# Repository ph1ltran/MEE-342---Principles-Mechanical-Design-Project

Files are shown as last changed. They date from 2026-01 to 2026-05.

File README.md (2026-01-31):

# MEE-342---Principles-Mechanical-Design-Project
Spring 2026 Semester - Group 13

Team members: Chase Winkelmann, Samantha Perek, Aza Zandieh, Phil Tran, Jon Seddon, Mahima Dattaguru

Main Report: should link to section-specific markdown files if needed (e.g., phase1.md, phase2.md, phase3.md).

[Phase 1 - System Understanding & Conceptual Design](https://github.com/ph1ltran/MEE-342---Principles-Mechanical-Design-Project/blob/main/phase1.md)

[Phase 2 - Detailed CAD Design & Engineering Analysis](https://github.com/ph1ltran/MEE-342---Principles-Mechanical-Design-Project/blob/main/phase2.md)

[Phase 3 - Prototyping, Testing, & Reflection](https://github.com/ph1ltran/MEE-342---Principles-Mechanical-Design-Project/blob/main/phase3.md)

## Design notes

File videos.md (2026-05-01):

# Links or text files pointing to hosted videos (e.g., YouTube links).

## Phase 1 Video
### Presentation
[Phase 1 Video](https://drive.google.com/file/d/13TvbBJ1mibGNusMHqBIKrH3WXQ0-EbeE/view?usp=sharing)

## Phase 2 Videos
### Presentation
[Phase 2 Video](https://drive.google.com/file/d/1klvvWlFgjiC-BsxMcsrkD3P9RIFnxmCl/view?usp=sharing)

### CAD/FEA Overview
https://github.com/user-attachments/assets/684e30f0-5ba8-4716-a56b-c2a44ff6e8ca

## Phase 3 Video
[Phase 3 Video](https://drive.google.com/file/d/16Yx-jXtcq2Cfcu958getdcPu3kcB0Ceg/view?usp=sharing)

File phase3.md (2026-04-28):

## Prototype Pictures:

Prototype Picture 1
Prototype Picture 2

## Fabrication Details:
Number of Parts: 2

Units: inches

Dimensions (WxLxH):

Support: 6x6x7

Holder: 6x2x3

Infill Density: 100%

Color: Grey

Number of Reprints: None

## Assembly Procedure:
1. Align the hole of the device holder between the two holes of the angled support. Ensure that the holder has the correct orientation and is facing the right direction.

2. Insert the threaded bolt through the hole, joining the holder to the support.

3. Once the bolt has been completely inserted, thread the wingnut onto the end of the bolt and tighten until the holder is no longer loose and its position remains fixed.

4. To change the holder’s position, simply loosen the wingnut to adjust the position before tightening the wingnut once again.

## Assembly Challenges:
The first challenge encountered in the assembly process was exporting the CAD model to an STL file as required by the FSE 3D Print Lab. Since the original CAD model was designed using the student version of ANSYS DesignModeler in order to facilitate the FEA procedures in Phase 2, exporting to an STL file was initially not an option. Multiple remedies to this obstacle were considered, such as transferring the model over to SpaceClaim for export or finding individuals with the full version of ANSYS who could then export the model to an STL file. Eventually, it was decided to redesign the model in SolidWorks while referencing the ANSYS model for the original design dimensions. This allowed the model to finally be exported to an STL file for 3D printing.

The second challenge encountered was that the bolt was not able to be smoothly inserted into the hole joining the holder to the support, due to insufficient tolerance in the dimensions of the original design. However, this turned out to not be a significant problem, because applying sufficient force allowed the bolt to be completely inserted while firmly securing the holder to the support with the tightening of a wingnut.

## Test Procedures, Results, and Interpretation:
After assembling the 3D printed prototype, several different loads were applied to the structure in order to analyze its functionality. Not only was it able to withstand the weight of an iPhone, but also that of an iPad despite the decision to reduce its dimensions and change the intended load in Phase 2 of this project. The prototype is also capable of providing multiple viewing angles by simply loosening or tightening the wingnut and changing the position of the holder, as intended.

## Comparison with Phase 2 Predictions:
When discussing the risks associated with the stand, we were worried about the stand being too top-heavy and tipping. This was not an issue, since the material used to 3-D print was much sturdier than we anticipated. Although it was designed to hold a phone, it can successfully hold the weight of an iPad without tipping and without the bolt failing. We did not have to redesign the size of any part of the stand; they all worked as anticipated. The assessment of the factor of safety also seems accurate, since we tested the stand with heavier weights than the iPhone, and it did not tip or break.

## Detailed Discussion of Failures, Mistakes, and Surprises:
As mentioned previously, one surprise during the project was that the student version of ANSYS did not allow exporting the CAD model to an STL file. Fortunately, redesigning the model in SolidWorks solved this problem and allowed the project to proceed onwards with 3D printing. Another surprise happened after assembling the model and testing what it could hold. The material was much stronger than expected, and it was able to withstand more weight than was assumed.

## List of Design Changes for a Hypothetical “Version 2”:
If a second iteration of this project was run, some design changes/decisions that would be implemented in the future are:

1. Creating the model in SolidWorks first, then importing into ANSYS to avoid dealing with the issue of exporting to STL for 3D printing

2. The part of the stand that holds the phone should have a hole in the bottom to allow people to charge their phone while it's on the stand

3. The lip of the stand should be decreased in size because it blocks a lot of the phone screen. We were worried about the phone falling off the stand, but seeing how it functions, the large size of the lip is unnecessary

4. In general, the width of most parts of the stand could probably be decreased slightly to reduce the amount of material used

## Understanding of a Real World Hinged Device
In a device such as a laptop or adjustable phone stand, many different companies use different methods to achieve a self adjustable position. The most common design is frictional hinged rotation. This method uses a resistive torque to counteract any gravitational force or force applied from the weight of a phone. Inside the hinge, a central shaft is connected by two separate rotating bodies, while a series of frictional elements such as rubber, washers or clutching plates are compressed together from a loading. The compression then allows for a sort of rotating resistance, which can allow the hinge to move at a specified angle.

Example Laptop Hinge

The internal structure of a hinge (like the one in the image above) generally includes a cylindrical housing, a hardened steel shaft, friction components, and mounting brackets that attach to the device. The friction force is controlled by material selection and the amount of normal force applied between the contact surfaces. Materials such as stainless steel, brass, and polymer inserts are commonly used to balance durability, smooth motion, and wear resistance. In more advanced designs, additional elements such as torsion springs or damping systems may be included to improve performance, especially in heavier devices like laptops where maintaining screen position is critical.

From a mechanical perspective, the hinge operates by balancing applied torque with internal frictional resistance. When a user opens or adjusts the device, the applied torque exceeds the frictional torque, allowing rotation. Once the external force is removed, the friction within the hinge prevents further motion, effectively holding the device in position.

Hinges must also meet strict design requirements, including compact size, long-term durability, and consistent performance over thousands of cycles. Over time, as next-generation computing devices become increasingly thinner in order to satisfy consumer demands, hinge designs have become increasingly complex with smaller diameters and volume to meet size constraints.  

Example Laptop Hinge 2

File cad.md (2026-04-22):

# Exported CAD files in neutral formats (STEP, STL).

Phone Bracket Holder:
[Phone Bracket Holder.STL](https://github.com/ph1ltran/MEE-342---Principles-Mechanical-Design-Project/blob/9b1efe38d610628d663854d1fb47e2206d6566ca/Phone%20Bracket%20Holder.STL)

L Stand:
[L_Stand.STL](https://github.com/ph1ltran/MEE-342---Principles-Mechanical-Design-Project/blob/7d2d80c046e3e7f969235f0f32def2235fa828c3/L%20Stand.STL)

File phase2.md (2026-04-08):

## Overview of Final Design (w/ key CAD images)
### Video
https://github.com/user-attachments/assets/684e30f0-5ba8-4716-a56b-c2a44ff6e8ca

### Images
FEA Geometry
FEA Side Profile
FEA Equivalent Stress
FEA Shear Stress
FEA Total Deformation

## Description of Major Design Decisions/Changes from Phase 1
Since the completion of Phase 1 of this project, a few major decisions as well as design changes have been made by the team in order to satisfy printability and CAD requirements. 

Firstly, it was decided that the CAD model as well as the 3D-printed prototype of the adjustable iPad stand will be significantly scaled down compared to the original product. In addition, an iPhone will be used as the reference load instead of an iPad, even though the reverse-engineered product is meant to be an adjustable iPad stand. These decisions were made because the Fulton Schools 3D Print Lab has limited the max build plate size to dimensions of 250 x 210 x 210 mm, which restricts the dimensions of the device holder because some iPads have dimensions which exceed these limits. For example, the iPad Pro 13-inch has dimensions of 281.6 x 215.5 x 5.1 mm, so designing a steady holder for this model (without the possibility of the device tipping off the sides of the holder) using the 3D Print Lab would be difficult.

Secondly, it was decided that the angled support of the iPad stand will need to be designed with fillets in the angled part. The initial sketch of this component in Phase 1, which is shown in the figure below, did not include any fillets in this area and would therefore have resulted in stress singularities in the CAD/FEA model. However, it is known from finite element analysis that a common technique to prevent stress singularities in sharp corners is to add fillets. This technique will be utilized in this project in order to prevent this potential issue from occuring during the CAD testing phase.

Phase 1 Sketch of Angled Support

## Detailed Explanations of Required Analyses, Assumptions, and Results
### 1. Static Stress and Factor of Safety

The critical part evaluated from the static stress and factor of safety analysis is the holder. Using basic mechanics of materials and assuming that this part does not experience any torsional loads, the combined stress in the long part of the holder was calculated to be about 8 psi       and the combined stress around the edge of the hole was calculated to be about 2.85 psi, which agrees with the solution obtained from ANSYS (see FEA figures). The max combined stress in the holder, however, is expected to occur in the location where the cross section       of the part is reduced due to the hole’s presence. This value was calculated to be about 1000 psi, which does not agree with the solution from ANSYS which lists the max stress as just 16.911 psi in this area. But since ANSYS’ result is located at a sharp corner, it is concluded that     this result is actually a stress singularity, so the true max combined stress is expected to be around 1000 psi in the holder. Lastly, with structural steel as the selected material, the factor of safety was calculated to be FS = 36250/1000 = 36.25.

Statics Image 1
Statics Image 2

### 2. Fatigue Assessment

By using the ‘fatigue tool’ in ANSYS for fully-reversed loading and analyzing the Goodman line under Mean Stress Theory, the mean stress of the adjustable stand was estimated to be (1 + (-1))/2) = 0 psi and the alternating stress was estimated to be |(1 - (-1))/2)| = 1 psi. The fatigue factor of safety was also determined from ANSYS to be 15.

FEA Fatigue Tool
FEA Fatigue Safety Factor

### 3. Gear Tooth Loading

Not applicable - design doesn't involve gears.

### 4. Key / Coupling / Interface Stresses

Assuming that the external moment reaction acting on the holder is translated to a torsional moment acting on the bolt, which has a radius of 0.175 in, then the approximate max torsional shear stress of the bolt was computed as Tc/J = (0.5625 lb*in)(0.175 in)/(π/2 * 0.175^4 in^4) = 66.817 psi. This is reasonable for structural steel, because the factor of safety was computed as FS = 36250/66.817 = 542.527. Therefore, failure is not expected to occur in the bolt in comparison to other potential critical locations.

### 5. Bearing Load Check

Not applicable - design doesn't involve bearings.

### 6. Global Safety Overview

In summary, the critical location of the adjustable iPad stand is expected to be near the hole of the holder where the bolt is to be inserted. The computed factor of safety of this critical location is FS = 36.25 (see Static Stress and Factor of Safety for more details). On the other hand, the fatigue factor of safety was determined from ANSYS to be 15. This indicates that the iPad stand is more likely to succumb to fatigue failure than static failure. But since these safety factors were not exceedingly small, it was not necessary to implement any additional design modifications in order to achieve acceptable results.

## Discussion of Design for Assembly and 3D Printing
The assembly consists of four 3D-printed components: the stand, the iPad holder, a bolt, and a nut. The stand serves as the base structure, providing stability, while the iPad holder is designed to securely support the device at the desired angle. These two primary components are connected using the bolt, which passes through aligned holes in both the stand and the holder. The nut is then fastened onto the bolt to secure the connection, allowing the assembly to remain stable while also enabling easy adjustment or disassembly if needed. The nut and bolt system allows the holder to be “locked” at the desired position.

## Updated List of Anticipated Risks/Weaknesses to be Addressed in Prototyping
The first risk that had to be considered in designing the stand was making sure it was not too top-heavy, or else it would tip over. The starting design for the part of the stand that holds the phone is a J-shaped piece with a height of 7 inches, a width of 4 inches, and a thickness of 0.25 inches. These measurements will give the phone enough support while still having a reasonable weight. During prototyping, this will be tested to see if any changes need to be made to the dimensions of the holder. Another risk that was found during phase one is making sure the angled base does not snap at the corner. The increased risk is due to the corner being a stress concentration, both in the FEA model and in the physical one. To remove this stress concentration, a fillet was added to the inside of the base, decreasing the amount of stress placed on that area. The final risk is the tightening bolt that will be used to adjust the holder and keep it in place. So far, the design for that has not changed, but it will be something to focus on during prototyping.

## How Does a Real Device Stand Work?
A real adjustable device stand works mainly through friction, gravity, and structural geometry. Instead of using a threaded bolt or screw, these stands often rely on hinges with built-in friction or are made from flexible materials that resist movement. When a device is placed on the stand, the weight of the device creates a downward force, which translates into a frictional force at the hinge or contact surfaces, preventing the stand from moving.
The angle of the support arms is critical. By designing the arms to be triangular or L-shaped, the design is able to take advantage of triangular load distribution, which is one of the most stable geometric shapes in mechanics. This helps reduce bending moments and torque at the hinge, improving stability. The center of gravity of the device and the stand is positioned so that it falls within the base area, which prevents tipping.
Material selection also plays an important role in a real device stand. Materials with some elasticity or flexibility allow the hinge to resist small rotations while still being adjustable. Surfaces in contact with the device are often lined with high-friction materials like rubber or silicone, increasing the static friction coefficient, which resists sliding. Some stands use spring-loaded or tensioned hinges, which generate an internal counteracting torque to balance the weight of the device at different angles.
In short, the stand functions by combining mechanical equilibrium, torque resistance, frictional forces, material stiffness, and weight distribution. These engineering principles ensure the device remains stable at the desired angle without manual locking mechanisms, while still being adjustable and easy to use.

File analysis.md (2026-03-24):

# Calculations, spreadsheets, scripts, or summaries of FEA/motion analyses.

## Static Stress and Factor of Safety

The critical part evaluated from the static stress and factor of safety analysis is the holder. Using basic mechanics of materials and assuming that the part does not experience any torsional loads, the combined stress in the long part of the holder was calculated to be about 8 psi       and the combined stress around the edge of the hole was calculated to be about 2.85 psi, which agrees with the solution obtained from ANSYS (see FEA figures for comparison). The max combined stress in the holder, however, is expected to occur in the location where the cross section       of the part is reduced due to the hole’s presence. This value was calculated to be about 1000 psi, which does not agree with the solution from ANSYS which lists the max stress as just 16.911 psi in this area. But since ANSYS’ result is located at a sharp corner, it is concluded that     this value is actually a stress singularity, so the true max combined stress is expected to be around 1000 psi in the holder. Lastly, with structural steel as the selected material, the factor of safety was calculated to be FS = 36250/1000 = 36.25.

Statics Image 1
Statics Image 2

## Fatigue Assessment

By using the ‘fatigue tool’ in ANSYS for fully-reversed loading and analyzing the Goodman line under Mean Stress Theory, the mean stress of the adjustable stand was estimated to be (1 + (-1))/2) = 0 psi and the alternating stress was estimated to be |(1 - (-1))/2)| = 1 psi. The fatigue factor of safety was also determined from ANSYS to be 15.

FEA Fatigue Safety Factor
FEA Fatigue Tool

## Finite Element Analysis (FEA)
### Video
https://github.com/user-attachments/assets/684e30f0-5ba8-4716-a56b-c2a44ff6e8ca

### Images
FEA Geometry
FEA Side Profile
FEA Equivalent Stress
FEA Shear Stress
FEA Total Deformation

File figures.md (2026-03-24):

# Images used in the report (diagrams, CAD screenshots, photos, etc.).

## Component Breakdown
Component Motion

## Kinematic Diagram
Kinematic Diagram

## CAD/FEA Images
FEA Geometry
FEA Side Profile
FEA Equivalent Stress
FEA Shear Stress
FEA Total Deformation
FEA Fatigue Safety Factor
FEA Fatigue Tool

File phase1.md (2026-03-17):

## Executive Summary
An iPad stand is a common yet versatile accessory designed to hold an iPad (or other physically similar devices) in an adjustable, hands-free position that provides an optimal viewing angle for the user. It is typically found in home or office settings and is used for everyday applications such as studying, video conferencing, media consumption, and gaming, while providing improved ergonomics, increased comfort, reduced neck and eye strain, reduced wrist fatigue, and increased device stability.

This project, assigned as part of the MEE 342: Principles of Mechanical Design course at Arizona State University, will involve the reverse-engineering (studying, modelling, documenting, 3D printing, and prototyping) of an iPad stand. Several key factors will need to be considered with regard to the functionality and feasibility of this mechanical system. For example, the iPad Stand is expected to remain balanced on a level surface while it is subjected to its intended load, which can have different directions depending on how the holder is positioned. The iPad stand will be capable of rotating to multiple viewing angles, resulting in changing load paths and boundary conditions that increase the importance of proper stress-strain analysis. In addition, finite element analysis (FEA) will need to be performed on the system to ensure that it will not experience excessive stress or deformation that would cause structural failure. Other design fundamentals and skills, including but not limited to material selection, failure modes, and computer-aided design (CAD), will also be applied to the design process of the iPad Stand.  

## System Description & Functional Overview
The iPad stand should be assembled from three main components: an angled support, a lipped-device holder, a threaded pin connecting the support to the holder and an adjustable nut to tighten the connection. The angled support should be able to balance the entire assembly on a level surface for any adjustment of the holder, regardless of it being subjected to a load from the weight of the device. To equate this, the centre of mass as well as tipping moments will need to be calculated. This means that even without anything on it, the stand should still be able to support itself and not tip in any direction, which can be accomplished by adding a heavy weight to the bottom of the support. The lipped-device holder should be able to support the weight of the device that is placed upon it while not tilting itself. To be considered functional, its position can only be adjusted when an external load (not the device's weight) is applied by the user. The third and final key set of components within the system is the threaded pin and corresponding nut that secures the support to the holder. The threaded pin should be fastened with the nut, allowing the user to position the angle as desired.  

In regards to operating conditions, the iPad stand is expected to be used at room temperatures (68-77°F) within indoor environments such as homes, offices, classrooms, or libraries. It should not be frequently exposed to open weather conditions such as rain, dust, or snow, as these elements could damage the iPad, cause rusting of the components, or build up within the hinge of the stand thereby limiting its mechanical functionality. The iPad stand is also expected to be used on flat, stable surfaces such as desks, tables, or countertops, and the stand must be able to resist sliding or tipping on low-friction surfaces. Lastly, the stand will be designed with the intention of supporting the weight of an iPad or other physically similar device. The stand is not expected to be able to support any device that is significantly larger or heavier than an iPad.

## Component Breakdown
iPad_Stand_Component_Motion

## Kinematic Description & Critical Design Parameters
Our iPad stand is a 1-degree-of-freedom adjustable mechanism. The support arm rotates about a single hinge, creating a circular motion path about the hinge center, and the iPad platform rotates with the arm to change viewing angle. The range at which the iPad stand can adjust to is roughly a 180-degree angle, allowing a straight forward look, or backwards. Angle adjustment is achieved by loosening a threaded nut at the hinge, rotating the arm to the desired angle, and then tightening the nut to lock the position. Rotating the nut causes it to move along the threaded bolt by an amount given by the equation Δx = n·p, where each full turn moves the nut forward by one thread pitch, increasing or decreasing the clamping force that locks the arm’s angle. Tightening the nut (clockwise) increases friction at the hinge faces and prevents further rotation, while loosening the nut reduces clamp force and allows smooth repositioning between θ_min and θ_max mechanical limits. 
Kinematic Diagram

## Preliminary Failure Modes & Design Considerations
The most likely failure modes of the iPad stand are static overload and fatigue failure. We believe static overload could happen in two places: the first is in the mechanism that allows the iPad holder to be adjusted, and the second is in the angled part of the base. The mechanism has to be both adjustable and able to lock in place, so a tightening bolt will be used. This way, the iPad can be placed on it without fear of the mechanism giving out, and the bolt itself can be loosened so the stand can be adjusted as needed. Initially, a hinge was going to be used however the material constraints would make it far more difficult to achieve a functional hinge than a tightening bolt. The angled part of the base faces a large stress concentration from the weight of the iPad which will need to be focused on during the CAD testing phase. Since the iPad holder is for everyday use, it is possible that it could eventually face fatigue failure. To limit this, the threads of the bolt and the screw will be smoothed after they are printed, so there is no unwanted friction between the parts.

## References
INVZI MagFree Floating Magnetic Stand

https://all3dp.com/2/3d-printed-ipad-stand-tablet/ - This shows many different 3d printed iPad stands that we will use for references to what we might make, also talks about materials we could use

https://www.simplify3d.com/resources/materials-guide/properties-table/  - Filament properties table with all the different types of material for 3D printing

https://invzi.com/collections/magfree - Where the iPad stand from the picture came from

https://www.snapmaker.com/blog/how-long-does-it-take-to-3d-print-something/ - Knowledge about 3D printing time and how long it will take

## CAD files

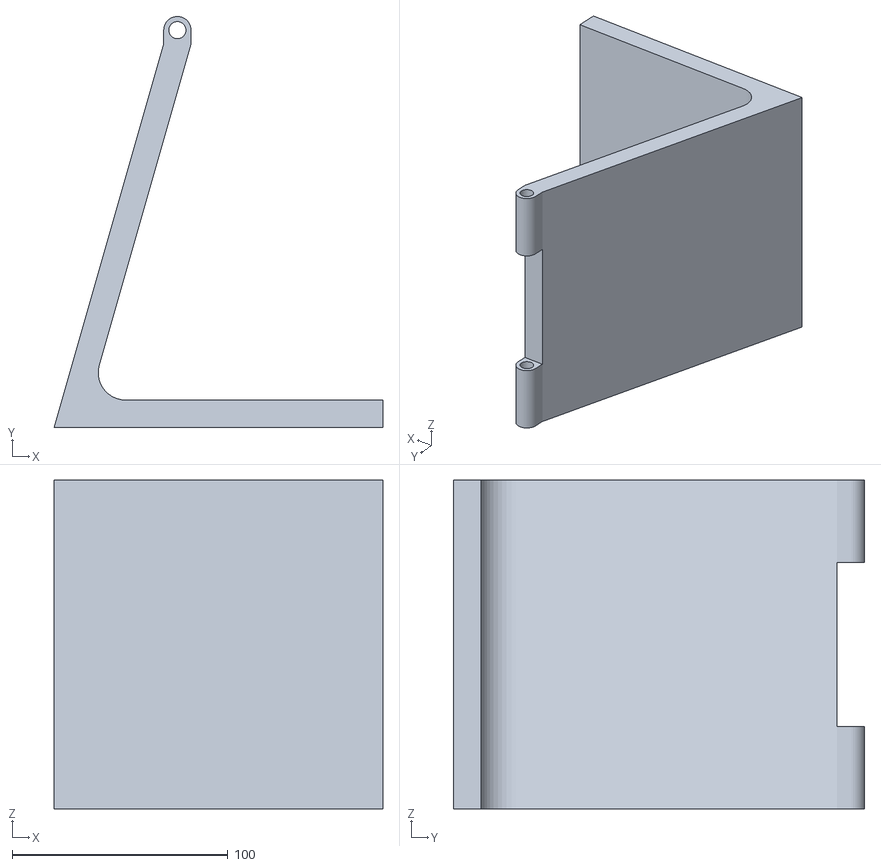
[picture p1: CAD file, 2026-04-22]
L Stand.STL
152.4 x 190.5 x 152.4

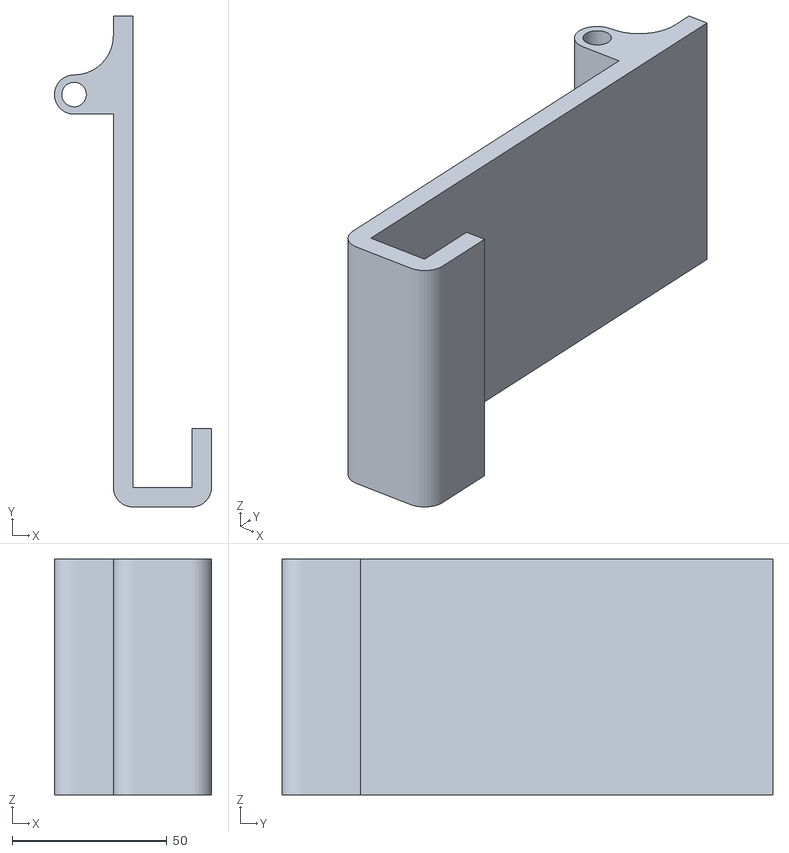
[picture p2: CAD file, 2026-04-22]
Phone Bracket Holder.STL
50.8 x 158.8 x 76.2

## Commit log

2026-01-25 Create cad
2026-01-25 Update cad
2026-01-25 Update and rename cad to cad.md
